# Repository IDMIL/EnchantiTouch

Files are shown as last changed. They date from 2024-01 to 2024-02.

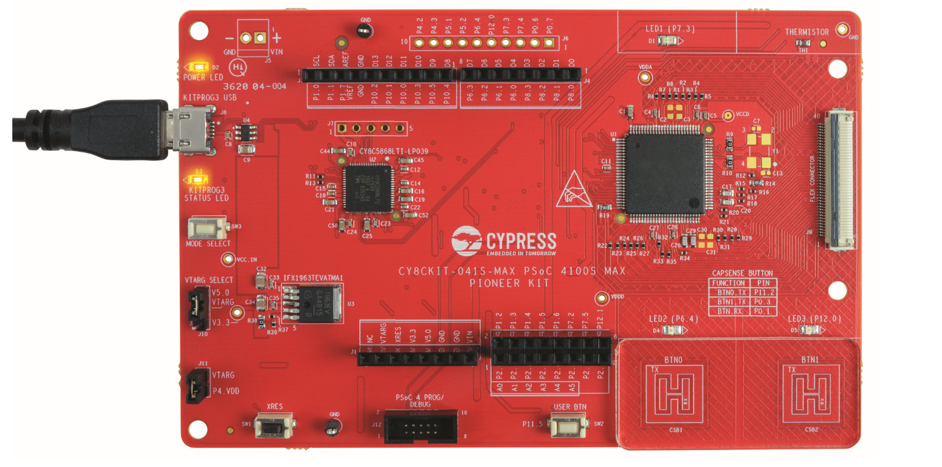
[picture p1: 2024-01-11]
firmware/tsticktouch_firmware/images/kit_connection.png

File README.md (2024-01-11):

# EnchantiTouch
This repository contains hardware files and firmware for the EnchantiTouch board. EnchantiTouch is a touch sensing board using Cypress' 4100S Max SoC. It supports up to 60 touch sensors through two 32 pin FFC connectors and multichannel scanning.

Branch archive-v0 features firmware for the first iteration of this board which did not have an SPI interface for communicating with a host MCU.

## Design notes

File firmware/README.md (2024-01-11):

# custom-touch-firmware
 Firmware for custom touch board for the T-Stick

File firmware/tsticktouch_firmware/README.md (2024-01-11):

# PSoC&trade; 4: Custom Touch Board for T-Stick

This code is meant to be used for collecting Touch Date to be sent to an external microcontroller. An additional touch board may be added vai SPI interface on the MCU

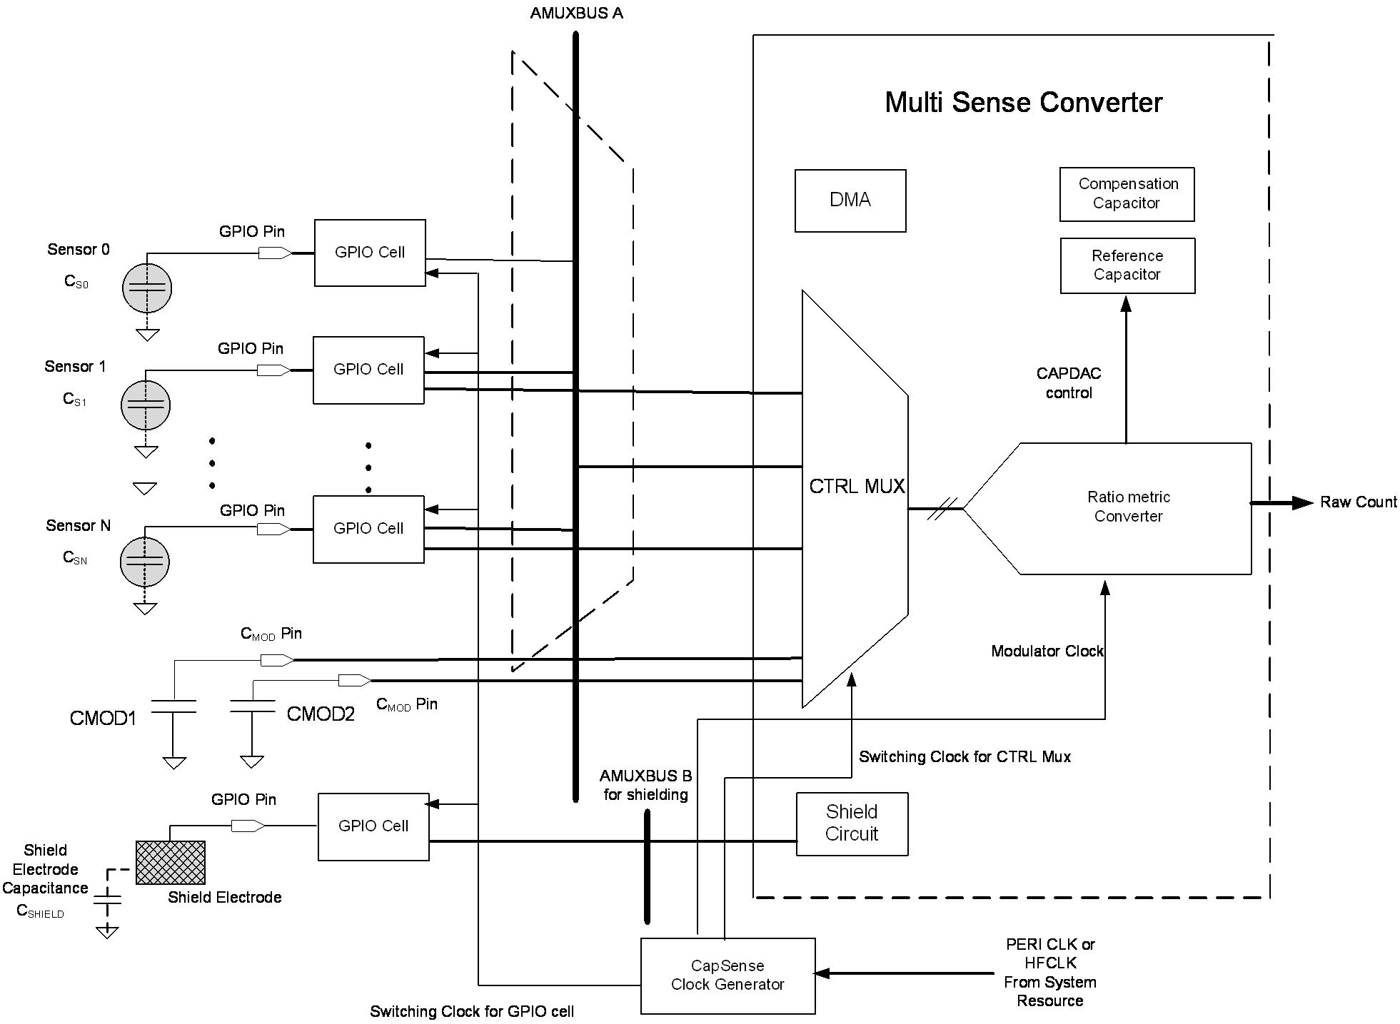
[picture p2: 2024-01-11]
firmware/tsticktouch_firmware/images/theory-blockdiagram.png

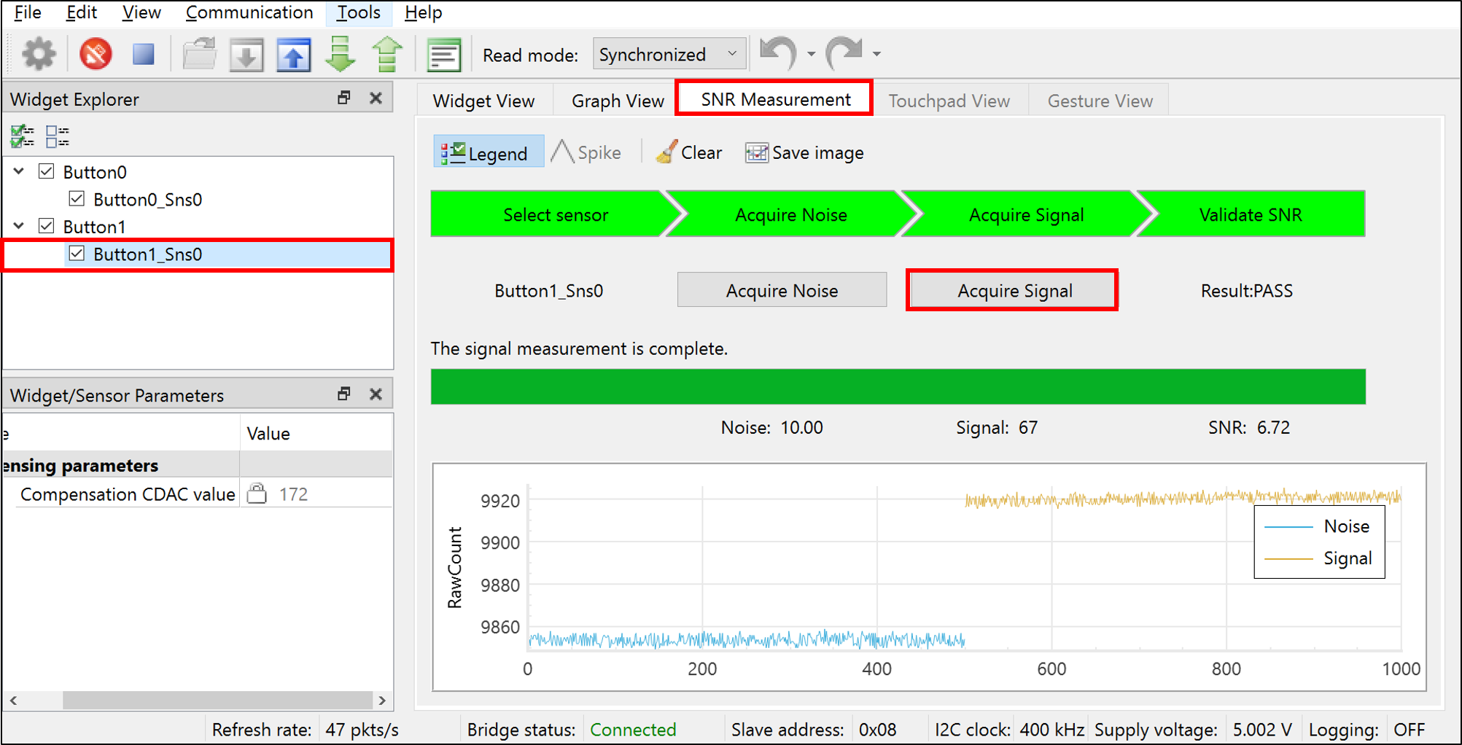
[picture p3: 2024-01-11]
firmware/tsticktouch_firmware/images/tuner-snr-pass.png

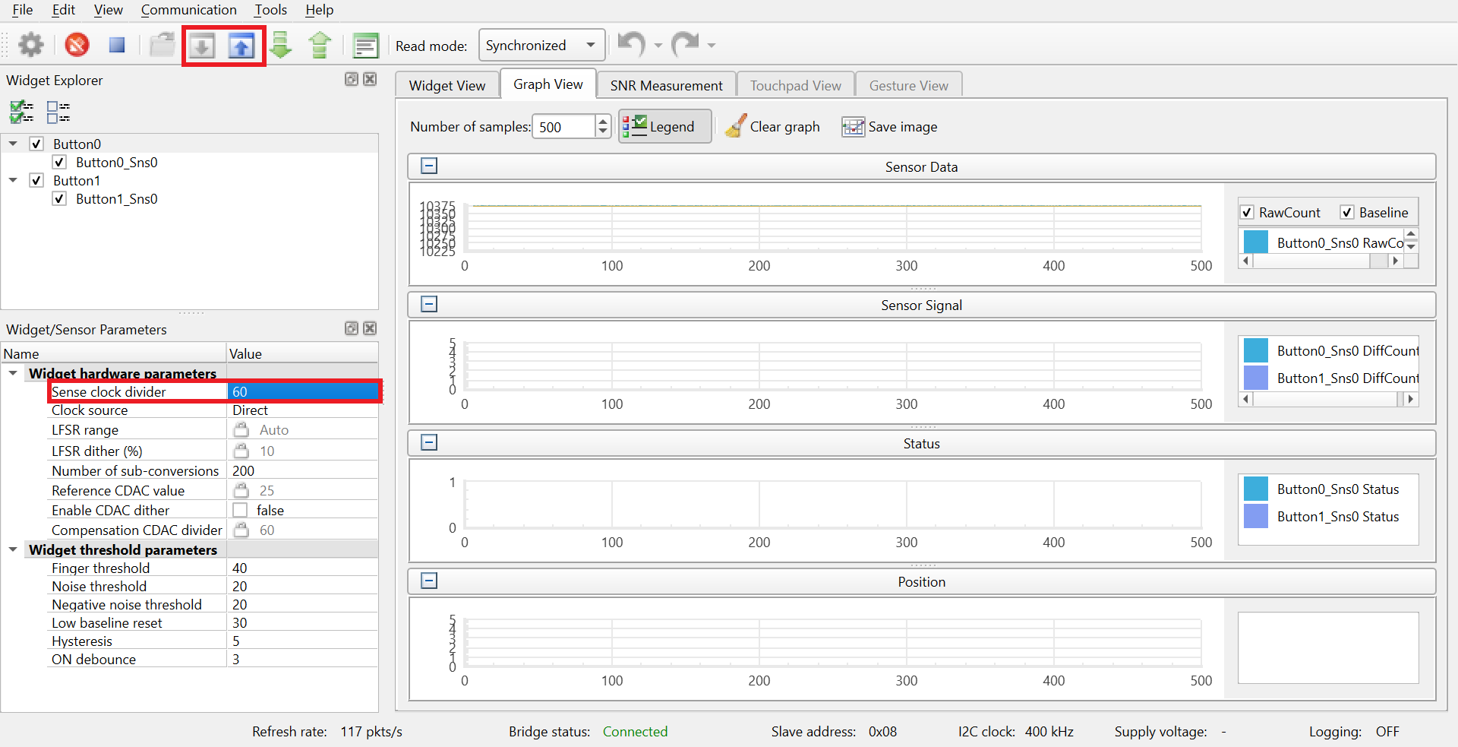
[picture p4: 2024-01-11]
firmware/tsticktouch_firmware/images/tuner-apply-to-device.png

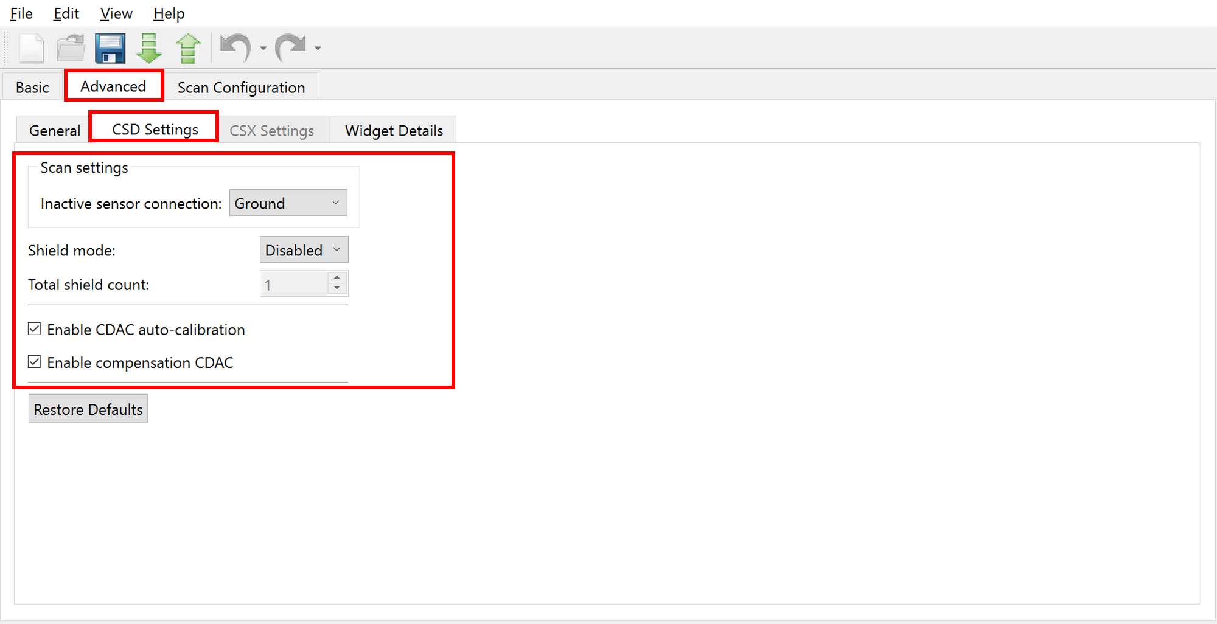
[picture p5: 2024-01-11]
firmware/tsticktouch_firmware/images/advanced-csd-settings.png

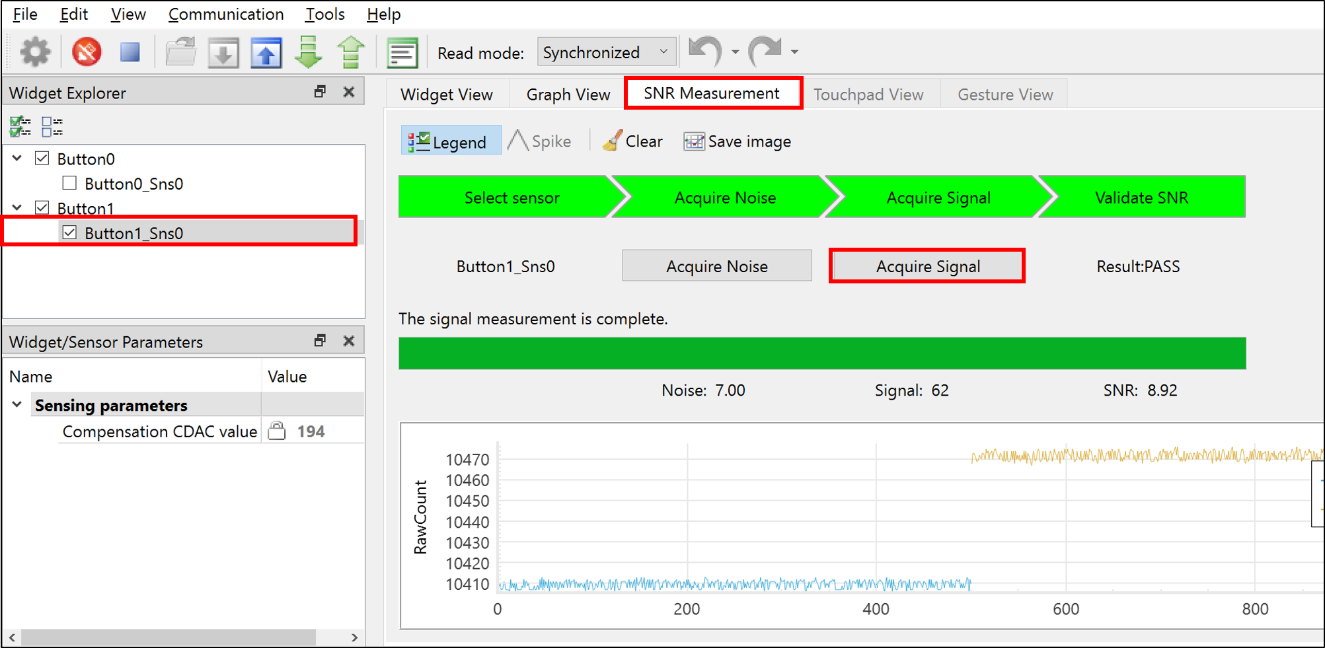
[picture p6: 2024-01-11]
firmware/tsticktouch_firmware/images/tuner-acquire-signal.png

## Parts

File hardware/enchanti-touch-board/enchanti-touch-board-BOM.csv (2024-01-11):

Manufacturer | MPN | Qty | Description | Reference(s) | Footprint
Murata Electronics | GCM155R71C104KA55J | 6 | 0.1 µF ±10% 16V Ceramic Capacitor X7R 0402 (1005 Metric) | C1, C10, C12, C14, C3, C5 | Capacitor_SMD:C_0402_1005Metric
Murata Electronics | GRM155R61C105KA12D | 6 | 1 µF ±10% 16V Ceramic Capacitor X5R 0402 (1005 Metric) | C11, C13, C15, C18, C2, C4 | Capacitor_SMD:C_0402_1005Metric
Murata Electronics | GRM155R71H222JA01J | 4 | 2200 pF ±5% 50V Ceramic Capacitor X7R 0402 (1005 Metric) | C6, C7, C8, C9 | Capacitor_SMD:C_0402_1005Metric
Micro Commercial Co | ESD5V0D5-TP | 1 | 18.6V Clamp 11.6A (8/20µs) Ipp Tvs Diode Surface Mount SOD-523 | D1 | Diode_SMD:D_SOD-523
JST Sales America Inc. | BM04B-SRSS-TB | 4 | Connector Header Surface Mount 4 position 0.039" (1.00mm) | GPIO1, GPIO2, GPIO3, GPIO4 | JST-footprints:JST_SH_BM04B-SRSS-TB_1x04-1MP_P1.00mm_Vertical
CNC Tech | 3220-10-0300-00 | 1 | Connector Header Surface Mount 10 position 0.050" (1.27mm) | J2 | Connector_PinHeader_1.27mm:PinHeader_2x05_P1.27mm_Vertical_SMD
Panasonic Electronic Components | ERJ-1GNF3300C | 2 | 330 Ohms ±1% 0.05W, 1/20W Chip Resistor 0201 (0603 Metric) Thick Film | R1, R2 | Resistor_SMD:R_0201_0603Metric
Panasonic Electronic Components | ERJ-1GNF5600C | 60 | 560 Ohms ±1% 0.05W, 1/20W Chip Resistor 0201 (0603 Metric) Thick Film | R3, R4, R5, R6, R7, R8, R9, R10, R11, R12, R13, R14, R15, R16, R17, R18, R19, R20, R21, R22, R23, R24, R25, R26, R27, R28, R29, R30, R31, R32, R33, R34, R35, R36, R37, R38, R39, R40, R41, R42, R43, R44, R45, R46, R47, R48, R49, R50, R51, R52, R53, R54, R55, R56, R57, R58, R59, R60, R61, R62 | Resistor_SMD:R_0201_0603Metric
Panasonic Electronic Components | ERJ-1GNF4701C | 2 | 4.7 kOhms ±1% 0.05W, 1/20W Chip Resistor 0201 (0603 Metric) Thick Film | R63, R64 | Resistor_SMD:R_0201_0603Metric
Molex | 54132-3262 | 2 | 32 Position FFC, FPC Connector Contacts, Bottom 0.020" (0.50mm) Surface Mount, Right Angle | TOUCH1, TOUCH2 | ffc_footprints:CON_541323262_MOL
Infineon Technologies | CY8C4149AZI-S598 | 1 | ARM® Cortex®-M0+ PSOC® 4 CY8C4100S Microcontroller IC 32-Bit 48MHz 384KB (384K x 8) FLASH 100-TQFP (14x14) | U1 | CY8C4149AZI-S598-footprints:QFP-100

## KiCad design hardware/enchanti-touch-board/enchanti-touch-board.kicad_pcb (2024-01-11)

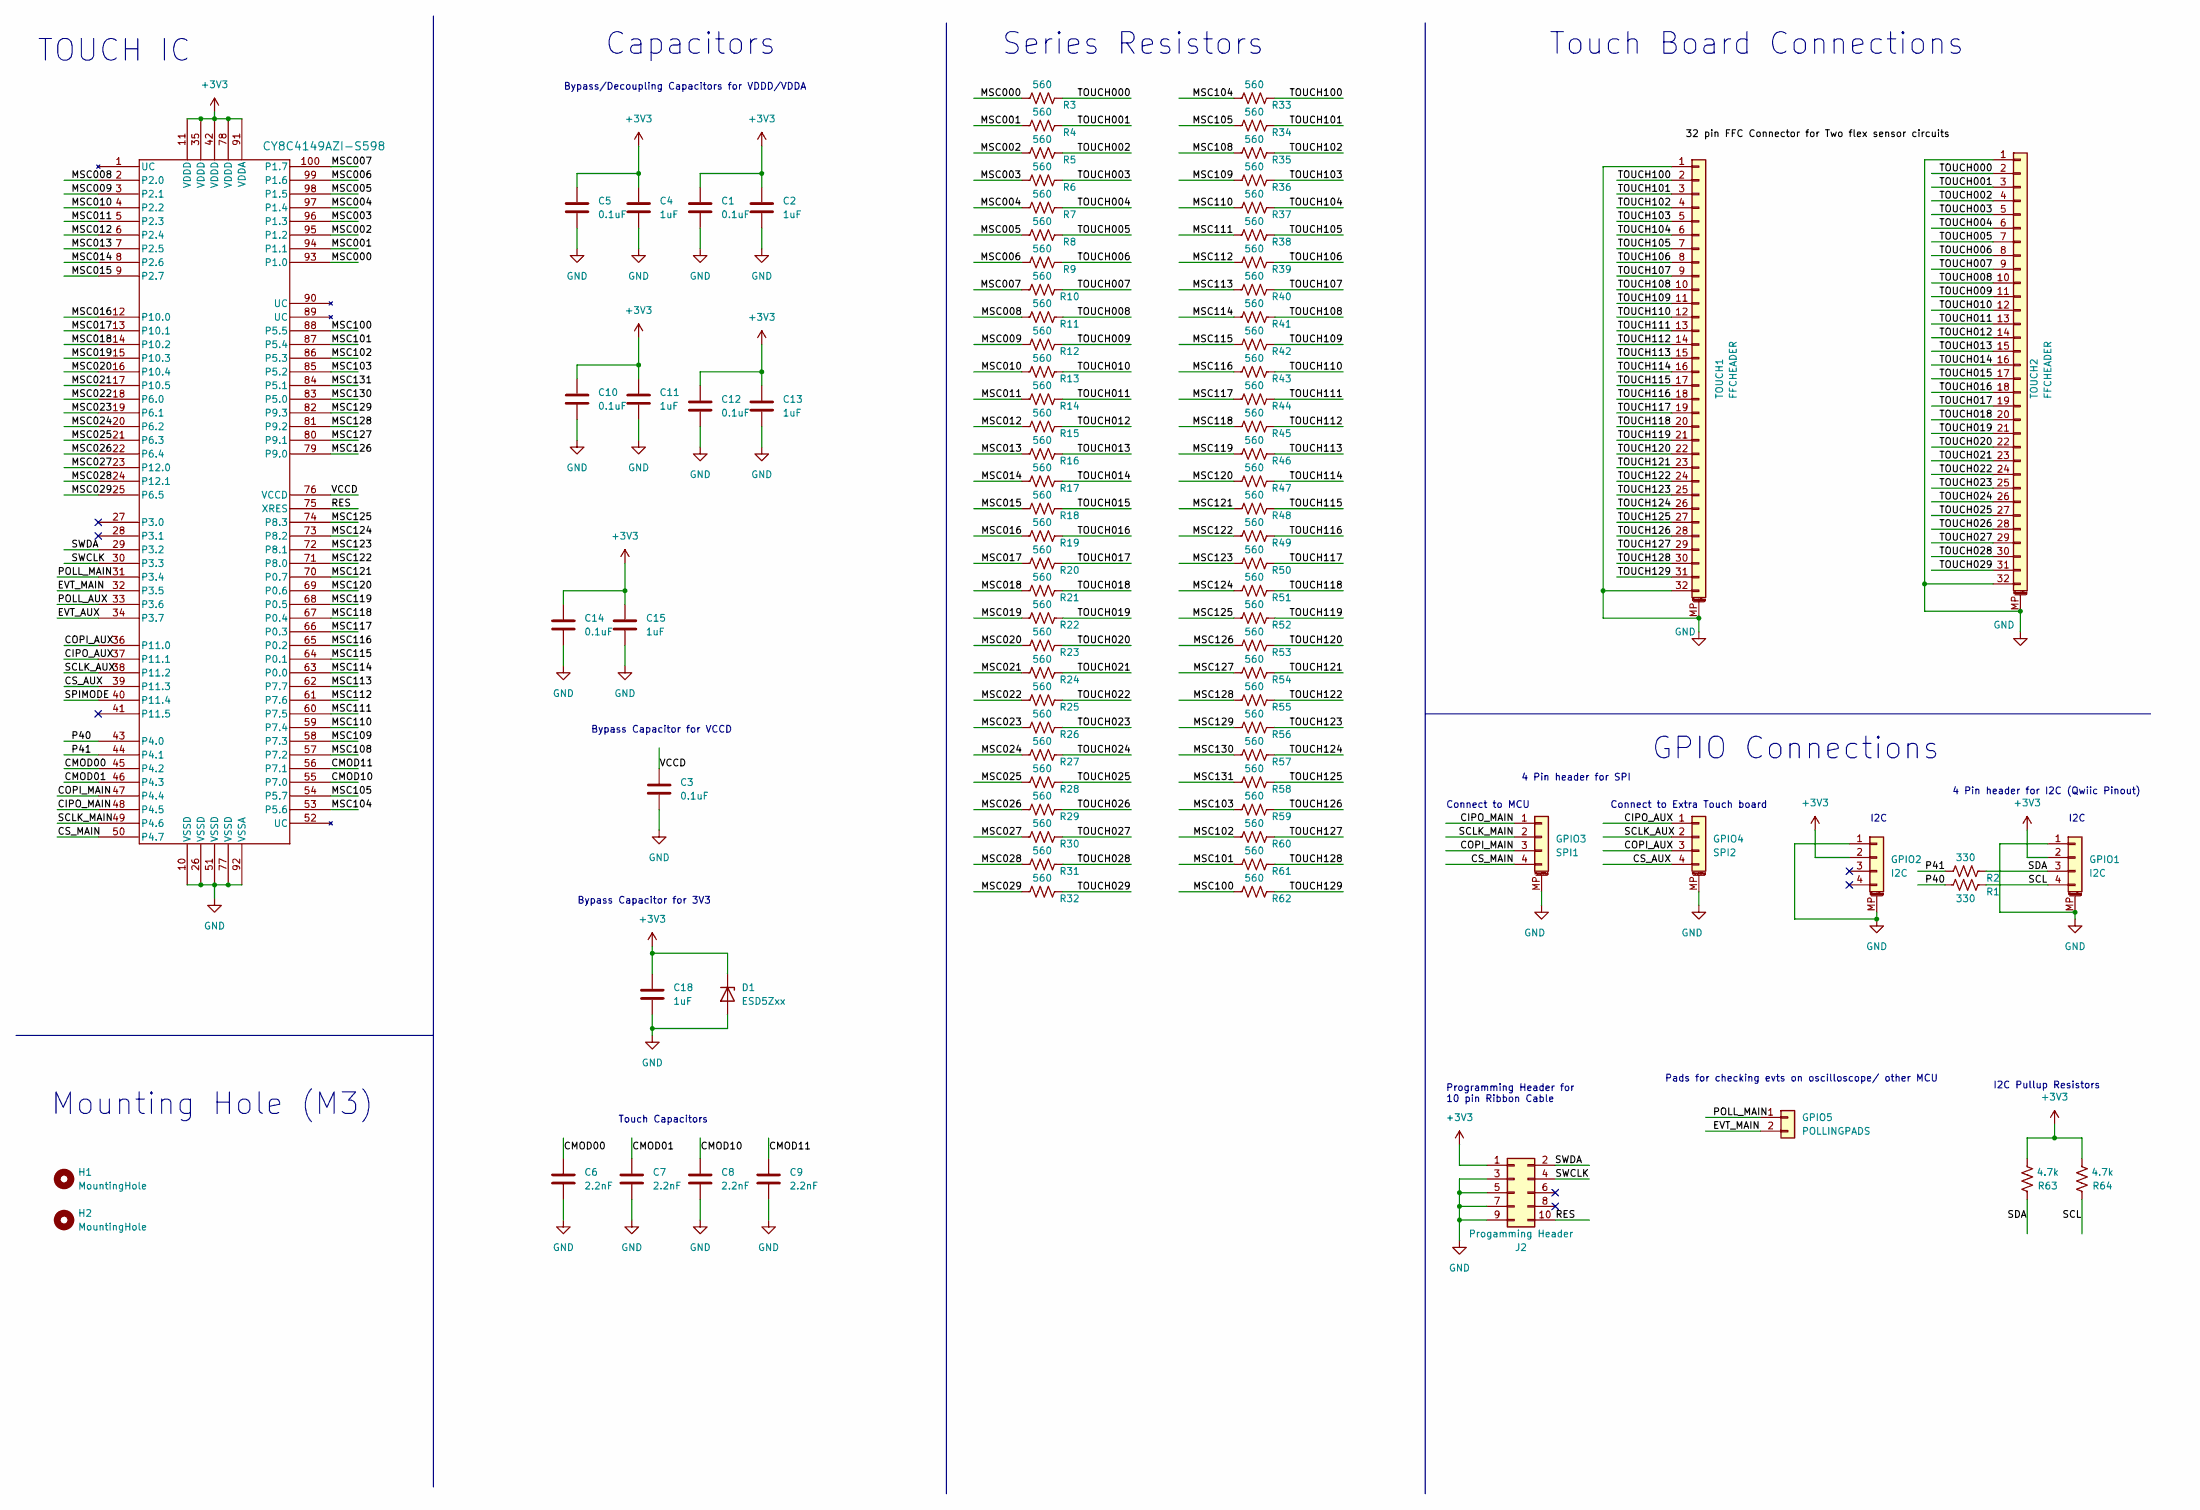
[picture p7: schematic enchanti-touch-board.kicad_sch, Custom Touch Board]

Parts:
C1, C3, C5, C10, C12, C14: 0.1uF; C_0402_1005Metric; MPN GCM155R71C104KA55J
C2, C4, C11, C13, C15, C18: 1uF; C_0402_1005Metric; MPN GRM155R61C105KA12D
C6, C7, C8, C9: 2.2nF; C_0402_1005Metric; MPN GRM155R71H222JA01J
D1: ESD5Zxx; D_SOD-523; MPN ESD5V0D5-TP
GPIO1, GPIO2: I2C; JST_SH_BM04B-SRSS-TB_1x04-1MP_P1.00mm_Vertical; MPN BM04B-SRSS-TB
GPIO3: SPI1; JST_SH_BM04B-SRSS-TB_1x04-1MP_P1.00mm_Vertical; MPN BM04B-SRSS-TB
GPIO4: SPI2; JST_SH_BM04B-SRSS-TB_1x04-1MP_P1.00mm_Vertical; MPN BM04B-SRSS-TB
GPIO5: POLLINGPADS; solderpads
H1, H2: MountingHole; MountingHole_3.2mm_M3
J2: Progamming Header; PinHeader_2x05_P1.27mm_Vertical_SMD; MPN 3220-10-0300-00
R1, R2: 330; R_0201_0603Metric; MPN ERJ-1GNF3300C
R3, R4, R5, R6, R7, R8, R9, R10, R11, R12, R13, R14, R15, R16, R17, R18, R19, R20, R21, R22, R23, R24, R25, R26, R27, R28, R29, R30, R31, R32, R33, R34, R35, R36, R37, R38, R39, R40, R41, R42, R43, R44, R45, R46, R47, R48, R49, R50, R51, R52, R53, R54, R55, R56, R57, R58, R59, R60, R61, R62: 560; R_0201_0603Metric; MPN ERJ-1GNF5600C
R63, R64: 4.7k; R_0201_0603Metric; MPN ERJ-1GNF4701C
TOUCH1, TOUCH2: FFCHEADER; CON_541323262_MOL; MPN 54132-3262
U1: CY8C4149AZI-S598; QFP-100; MPN CY8C4149AZI-S598

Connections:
+3V3: C1.2, C2.2, C4.2, C5.2, C10.2, C11.2, C12.2, C13.2, C14.2, C15.2, C18.2, D1.1 (K), GPIO1.2, GPIO2.2, J2.1, R63.2, R64.2, U1.11 (VDDD), U1.35 (VDDD), U1.42 (VDDD), U1.78 (VDDD), U1.91 (VDDA)
/CIPO_AUX: GPIO4.1, U1.37 (P11.1)
/CIPO_MAIN: GPIO3.1, U1.48 (P4.5)
/CMOD00: C6.2, U1.45 (P4.2)
/CMOD01: C7.2, U1.46 (P4.3)
/CMOD10: C8.2, U1.55 (P7.0)
/CMOD11: C9.2, U1.56 (P7.1)
/COPI_AUX: GPIO4.3, U1.36 (P11.0)
/COPI_MAIN: GPIO3.3, U1.47 (P4.4)
/CS_AUX: GPIO4.4, U1.39 (P11.3)
/CS_MAIN: GPIO3.4, U1.50 (P4.7)
/EVT_AUX: U1.34 (P3.7)
/EVT_MAIN: GPIO5.2, U1.32 (P3.5)
/MSC000: R3.1, U1.93 (P1.0)
/MSC001: R4.1, U1.94 (P1.1)
/MSC002: R5.1, U1.95 (P1.2)
/MSC003: R6.1, U1.96 (P1.3)
/MSC004: R7.1, U1.97 (P1.4)
/MSC005: R8.1, U1.98 (P1.5)
/MSC006: R9.1, U1.99 (P1.6)
/MSC007: R10.1, U1.100 (P1.7)
/MSC008: R11.1, U1.2 (P2.0)
/MSC009: R12.1, U1.3 (P2.1)
/MSC010: R13.1, U1.4 (P2.2)
/MSC011: R14.1, U1.5 (P2.3)
/MSC012: R15.1, U1.6 (P2.4)
/MSC013: R16.1, U1.7 (P2.5)
/MSC014: R17.1, U1.8 (P2.6)
/MSC015: R18.1, U1.9 (P2.7)
/MSC016: R19.1, U1.12 (P10.0)
/MSC017: R20.1, U1.13 (P10.1)
/MSC018: R21.1, U1.14 (P10.2)
/MSC019: R22.1, U1.15 (P10.3)
/MSC020: R23.1, U1.16 (P10.4)
/MSC021: R24.1, U1.17 (P10.5)
/MSC022: R25.1, U1.18 (P6.0)
/MSC023: R26.1, U1.19 (P6.1)
/MSC024: R27.1, U1.20 (P6.2)
/MSC025: R28.1, U1.21 (P6.3)
/MSC026: R29.1, U1.22 (P6.4)
/MSC027: R30.1, U1.23 (P12.0)
/MSC028: R31.1, U1.24 (P12.1)
/MSC029: R32.1, U1.25 (P6.5)
/MSC100: R62.1, U1.88 (P5.5)
/MSC101: R61.1, U1.87 (P5.4)
/MSC102: R60.1, U1.86 (P5.3)
/MSC103: R59.1, U1.85 (P5.2)
/MSC104: R33.1, U1.53 (P5.6)
/MSC105: R34.1, U1.54 (P5.7)
/MSC108: R35.1, U1.57 (P7.2)
/MSC109: R36.1, U1.58 (P7.3)
/MSC110: R37.1, U1.59 (P7.4)
/MSC111: R38.1, U1.60 (P7.5)
/MSC112: R39.1, U1.61 (P7.6)
/MSC113: R40.1, U1.62 (P7.7)
/MSC114: R41.1, U1.63 (P0.0)
/MSC115: R42.1, U1.64 (P0.1)
/MSC116: R43.1, U1.65 (P0.2)
/MSC117: R44.1, U1.66 (P0.3)
/MSC118: R45.1, U1.67 (P0.4)
/MSC119: R46.1, U1.68 (P0.5)
/MSC120: R47.1, U1.69 (P0.6)
/MSC121: R48.1, U1.70 (P0.7)
/MSC122: R49.1, U1.71 (P8.0)
/MSC123: R50.1, U1.72 (P8.1)
/MSC124: R51.1, U1.73 (P8.2)
/MSC125: R52.1, U1.74 (P8.3)
/MSC126: R53.1, U1.79 (P9.0)
/MSC127: R54.1, U1.80 (P9.1)
/MSC128: R55.1, U1.81 (P9.2)
/MSC129: R56.1, U1.82 (P9.3)
/MSC130: R57.1, U1.83 (P5.0)
/MSC131: R58.1, U1.84 (P5.1)
/P40: R1.1, U1.43 (P4.0)
/P41: R2.1, U1.44 (P4.1)
/POLL_AUX: U1.33 (P3.6)
/POLL_MAIN: GPIO5.1, U1.31 (P3.4)
/RES: J2.10, U1.75 (XRES)
/SCL: GPIO1.4, R1.2, R64.1
/SCLK_AUX: GPIO4.2, U1.38 (P11.2)
/SCLK_MAIN: GPIO3.2, U1.49 (P4.6)
/SDA: GPIO1.3, R2.2, R63.1
/SPIMODE: U1.40 (P11.4)
/SWCLK: J2.4, U1.30 (P3.3)
/SWDA: J2.2, U1.29 (P3.2)
/TOUCH000: R3.2, TOUCH2.2
/TOUCH001: R4.2, TOUCH2.3
/TOUCH002: R5.2, TOUCH2.4
/TOUCH003: R6.2, TOUCH2.5
/TOUCH004: R7.2, TOUCH2.6
/TOUCH005: R8.2, TOUCH2.7
/TOUCH006: R9.2, TOUCH2.8
/TOUCH007: R10.2, TOUCH2.9
/TOUCH008: R11.2, TOUCH2.10
/TOUCH009: R12.2, TOUCH2.11
/TOUCH010: R13.2, TOUCH2.12
/TOUCH011: R14.2, TOUCH2.13
/TOUCH012: R15.2, TOUCH2.14
/TOUCH013: R16.2, TOUCH2.15
/TOUCH014: R17.2, TOUCH2.16
/TOUCH015: R18.2, TOUCH2.17
/TOUCH016: R19.2, TOUCH2.18
/TOUCH017: R20.2, TOUCH2.19
/TOUCH018: R21.2, TOUCH2.20
/TOUCH019: R22.2, TOUCH2.21
/TOUCH020: R23.2, TOUCH2.22
/TOUCH021: R24.2, TOUCH2.23
/TOUCH022: R25.2, TOUCH2.24
/TOUCH023: R26.2, TOUCH2.25
/TOUCH024: R27.2, TOUCH2.26
/TOUCH025: R28.2, TOUCH2.27
/TOUCH026: R29.2, TOUCH2.28
/TOUCH027: R30.2, TOUCH2.29
/TOUCH028: R31.2, TOUCH2.30
/TOUCH029: R32.2, TOUCH2.31
/TOUCH100: R33.2, TOUCH1.2
/TOUCH101: R34.2, TOUCH1.3
/TOUCH102: R35.2, TOUCH1.4
/TOUCH103: R36.2, TOUCH1.5
/TOUCH104: R37.2, TOUCH1.6
/TOUCH105: R38.2, TOUCH1.7
/TOUCH106: R39.2, TOUCH1.8
/TOUCH107: R40.2, TOUCH1.9
/TOUCH108: R41.2, TOUCH1.10
/TOUCH109: R42.2, TOUCH1.11
/TOUCH110: R43.2, TOUCH1.12
/TOUCH111: R44.2, TOUCH1.13
/TOUCH112: R45.2, TOUCH1.14
/TOUCH113: R46.2, TOUCH1.15
/TOUCH114: R47.2, TOUCH1.16
/TOUCH115: R48.2, TOUCH1.17
/TOUCH116: R49.2, TOUCH1.18
/TOUCH117: R50.2, TOUCH1.19
/TOUCH118: R51.2, TOUCH1.20
/TOUCH119: R52.2, TOUCH1.21
/TOUCH120: R53.2, TOUCH1.22
/TOUCH121: R54.2, TOUCH1.23
/TOUCH122: R55.2, TOUCH1.24
/TOUCH123: R56.2, TOUCH1.25
/TOUCH124: R57.2, TOUCH1.26
/TOUCH125: R58.2, TOUCH1.27
/TOUCH126: R59.2, TOUCH1.28
/TOUCH127: R60.2, TOUCH1.29
/TOUCH128: R61.2, TOUCH1.30
/TOUCH129: R62.2, TOUCH1.31
/VCCD: C3.2, U1.76 (VCCD)
GND: C1.1, C2.1, C3.1, C4.1, C5.1, C6.1, C7.1, C8.1, C9.1, C10.1, C11.1, C12.1, C13.1, C14.1, C15.1, C18.1, D1.2 (A), GPIO1.1, GPIO1.MP (MountPin), GPIO2.1, GPIO2.MP (MountPin), GPIO3.MP (MountPin), GPIO4.MP (MountPin), J2.3, J2.5, J2.7, J2.9, TOUCH1.1, TOUCH1.32, TOUCH1.MP (MountPin), TOUCH2.1, TOUCH2.32, TOUCH2.MP (MountPin), U1.10 (VSSD), U1.26 (VSSD), U1.51 (VSSD), U1.77 (VSSD), U1.92 (VSSA)

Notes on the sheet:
Bypass Capacitor for VCCD
Touch Board Connections
I2C
Connect to Extra Touch board
Capacitors
Bypass/Decoupling Capacitors for VDDD/VDDA
Pads for checking evts on oscilloscope/ other MCU
GPIO Connections
Bypass Capacitor for 3V3
Mounting Hole (M3)
Connect to MCU
Touch Capacitors
4 Pin header for SPI
Series Resistors
I2C Pullup Resistors
4 Pin header for I2C (Qwiic Pinout)
TOUCH IC
Programming Header for 10 pin Ribbon Cable

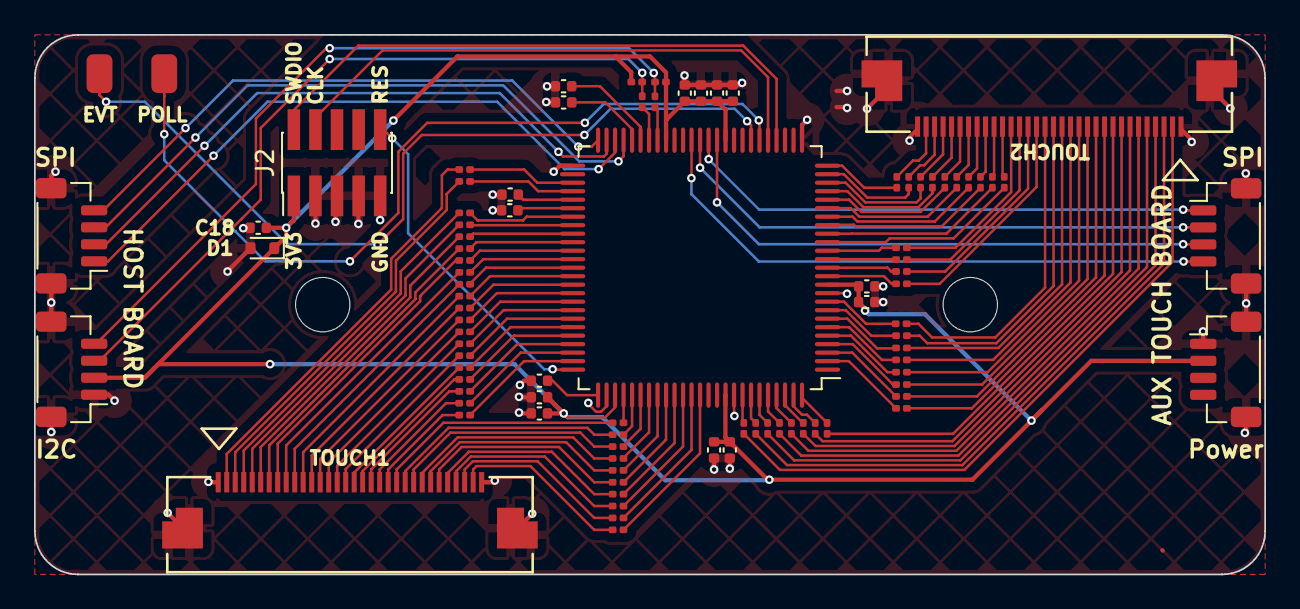
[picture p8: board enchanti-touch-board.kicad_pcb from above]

Board: 2 copper layers, 72.4 x 31.8 mm, 92 parts (0 on the bottom side), 144 nets.

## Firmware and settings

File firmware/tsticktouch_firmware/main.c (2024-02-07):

/******************************************************************************
* File Name: main.c
*
* Description: This is the source code for the PSoC 4 MSC CapSense CSD Button
* Tuning code example for ModusToolbox.
*
* Related Document: See README.md
*
*******************************************************************************
* Copyright 2021-2023, Cypress Semiconductor Corporation (an Infineon company) or
* an affiliate of Cypress Semiconductor Corporation.  All rights reserved.
*
* This software, including source code, documentation and related
* materials ("Software") is owned by Cypress Semiconductor Corporation
* or one of its affiliates ("Cypress") and is protected by and subject to
* worldwide patent protection (United States and foreign),
* United States copyright laws and international treaty provisions.
* Therefore, you may use this Software only as provided in the license
* agreement accompanying the software package from which you
* obtained this Software ("EULA").
* If no EULA applies, Cypress hereby grants you a personal, non-exclusive,
* non-transferable license to copy, modify, and compile the Software
* source code solely for use in connection with Cypress's
* integrated circuit products.  Any reproduction, modification, translation,
* compilation, or representation of this Software except as specified
* above is prohibited without the express written permission of Cypress.
*
* Disclaimer: THIS SOFTWARE IS PROVIDED AS-IS, WITH NO WARRANTY OF ANY KIND,
* EXPRESS OR IMPLIED, INCLUDING, BUT NOT LIMITED TO, NONINFRINGEMENT, IMPLIED
* WARRANTIES OF MERCHANTABILITY AND FITNESS FOR A PARTICULAR PURPOSE. Cypress
* reserves the right to make changes to the Software without notice. Cypress
* does not assume any liability arising out of the application or use of the
* Software or any product or circuit described in the Software. Cypress does
* not authorize its products for use in any products where a malfunction or
* failure of the Cypress product may reasonably be expected to result in
* significant property damage, injury or death ("High Risk Product"). By
* including Cypress's product in a High Risk Product, the manufacturer
* of such system or application assumes all risk of such use and in doing
* so agrees to indemnify Cypress against all liability.
*******************************************************************************/


/*******************************************************************************
 * Include header files
 ******************************************************************************/
#include "cy_pdl.h"
#include "cy_scb_spi.h"
#include "cybsp.h"
#include "cycfg.h"
#include "cycfg_capsense.h"
#include "cycfg_peripherals.h"
#include <stdint.h>
#include <stdio.h>
#include <time.h>
#include <sys/time.h>
#include <cy_systick.h>

/*******************************************************************************
* Macros
*******************************************************************************/
#define CAPSENSE_MSC0_INTR_PRIORITY      (3u)
#define CAPSENSE_MSC1_INTR_PRIORITY      (3u)
#define CY_ASSERT_FAILED                 (0u)
#define MSC_CAPSENSE_WIDGET_INACTIVE     (0u)

/* EZI2C interrupt priority must be higher than CapSense interrupt. */
#define EZI2C_INTR_PRIORITY              (2u)
#define SPI_INTR_PRIORITY                (2u)
#define SPI_AUX_INTR_PRIORITY            (2u)

/* Define Board Mode Macros*/
#define TOUCHSIZE (60u)
#define MAIN_TOUCH_BOARD (0u)
#define AUX_TOUCH_BOARD (1u)
#define SPI_TIMEOUT (1000)
#define SPI_BUFFERSIZE (128u)

/*******************************************************************************
* Global Variables
********************************************************************************/
cy_stc_scb_ezi2c_context_t ezi2c_context;
#if CY_CAPSENSE_BIST_EN
/* Variables to hold sensor parasitic capacitances and status*/
uint32_t button0_cp = 0, button1_cp = 0;
cy_en_capsense_bist_status_t button0_cp_status, button1_cp_status;
#endif /* CY_CAPSENSE_BIST_EN */
/* New touch variable (set to 1 if there is new touch data to send) **/
uint16_t newData = 0;
/* Touch data buffers*/
// Use 8bit subaddress size
typedef struct touchBuffer
{    
    uint8_t u8_reserve;                                    // addr 0, reserved for further use,
    uint8_t u8_boardmode;                                  // addr 1, is it the main board or aux board,
    uint8_t u8_numboards;                                  // addr 2, number of boards,
    uint8_t u8_touchmode;                                  // addr 3, reserved for further use,
    uint16_t u16_signal[TOUCHSIZE];                        // addr 4 - 124,
}touchBuffer;	

struct touchBuffer touch1Data; // Main board touch data
struct touchBuffer touch2Data; // Auxillary board touch data


/* Timing variables */
int start, end; // timing variable
float slot_scan_time = 0;
float sensor_scan_time = 0;
uint16_t scan_time = 0;
float total_t = 0;
int systick_count = 0;
float TRIALS = 20000.0f;
int SENSORS_PER_TRIAL = 30.0f;

/* Allocate context for SPI operation */
cy_stc_scb_spi_context_t spiContext;
cy_stc_scb_spi_context_t spi_aux_Context;
unsigned long transfer_status;
uint32_t bytes_transferred;
uint32_t spi_main_count;
uint32_t spi_aux_count;
uint16_t txBuffer[SPI_BUFFERSIZE];
uint16_t rxBuffer[SPI_BUFFERSIZE];
/* Define SPI Mode
    0 = Main board
    1 = Aux Board
*/
uint32_t BOARD_MODE = 0;
uint32_t ENABLE_SPI = 0;

/*******************************************************************************
* Function Prototypes
*******************************************************************************/
static void initialize_capsense(void);
static void capsense_msc0_isr(void);
static void capsense_msc1_isr(void);
static void saveTouchData(void);
static void ezi2c_isr(void);
static void spi_isr(void);
static void spi_aux_isr(void);
static void initialize_i2c(void);
static void initialize_spi(void);
static void getTouch(void);
static void sendTouch(void);
static float timedifference_msec(void);
static float timedifference_usec(void);
static void systick_isr(void);
static uint32_t get_tick(void);

#if CY_CAPSENSE_BIST_EN
static void measure_sensor_cp(void);
#endif /* CY_CAPSENSE_BIST_EN */

/*******************************************************************************
* Function Name: main
********************************************************************************
* Summary:
*  System entrance point. This function performs
*  - initial setup of device
*  - initialize CapSense
*  - perform Cp measurement if Built-in Self test (BIST) is enabled
*  - scan touch input continuously
*
* Return:
*  int
*
*******************************************************************************/
int main(void)
{
    cy_rslt_t result = CY_RSLT_SUCCESS;

    /* Initialize the device and board peripherals */
    result = cybsp_init();

    /* Board init failed. Stop program execution */
    if (result != CY_RSLT_SUCCESS)
    {
        CY_ASSERT(CY_ASSERT_FAILED);
    }

    /* Enable global interrupts */
    __enable_irq();

    /* Enable timer */
    Cy_SysTick_Init(CY_SYSTICK_CLOCK_SOURCE_CLK_CPU, 0x00FFFFFF);
    Cy_SysTick_SetCallback(0UL, &systick_isr);

    /* touch buffer Initialization */
    uint16_t i;  

    touch1Data.u8_reserve = 0x00u; 
    touch1Data.u8_boardmode = 0x00u;
    touch1Data.u8_numboards = 0x01u;
    touch1Data.u8_touchmode = 0x00u;   
    touch2Data.u8_reserve = 0x00u;   
    touch2Data.u8_boardmode = 0x00u;
    touch2Data.u8_numboards = 0x01u;
    touch2Data.u8_touchmode = 0x00u; 
    for(i=0; i<TOUCHSIZE; i++)
    {   
        // Main touch buffer
        touch1Data.u16_signal[i]   = 0x0000u;

        // Aux touch buffer
        touch2Data.u16_signal[i]   = 0x0000u;
    }

    /* Initialise SPI buffer*/
    for(i=0; i<SPI_BUFFERSIZE; i++)
    {   
        // Main touch buffer
        txBuffer[i]   = 0x0000u;
    }

    /* Initialize EZI2C */
    initialize_i2c();

    /* Initialize SPI*/
    initialize_spi();

    /* Initialize MSC CapSense */
    initialize_capsense();

#if CY_CAPSENSE_BIST_EN
    /* Measure the self capacitance of sensor electrode using BIST */
    measure_sensor_cp();
#endif /* CY_CAPSENSE_BIST_EN */
    /* start time */
    start = Cy_SysTick_GetValue();

    /* Start the first scan */
    Cy_CapSense_ScanAllSlots(&cy_capsense_context);

    for (;;)
    {
        if(CY_CAPSENSE_NOT_BUSY == Cy_CapSense_IsBusy(&cy_capsense_context))
        {
            /* Process all widgets */
            Cy_CapSense_ProcessAllWidgets(&cy_capsense_context);

            // /* Save touch data to touch buffers */
            saveTouchData();
            
            /* Start the next scan */
            Cy_CapSense_ScanAllSlots(&cy_capsense_context);

            /* If there are more than one touchboards get SPI data from them */
            if (touch1Data.u8_numboards > 1){
                getTouch();
            }

            /* Compute sensor scan time */
            end = get_tick();
            total_t = timedifference_usec();
            scan_time = (uint16_t)total_t;
            start = end;

            /* Send data to host MCU */
            sendTouch();

            // /* Toggles GPIO for refresh rate measurement. Probe at P3.4. */
            Cy_GPIO_Inv(CYBSP_SENSE_SCAN_RATE_PORT, CYBSP_SENSE_SCAN_RATE_NUM);

            // /* Sends interrupt if there is touch data */
            if (newData) {
                Cy_GPIO_Inv(CYBSP_EVT_PORT, CYBSP_EVT_NUM);
                newData = 0;
            }                
        }
    }
    // /* update time */
    // end = get_tick();
    // total_t = timedifference_sec();
    // slot_scan_time = 1000 * total_t / TRIALS; // scan time per 30 sensors (us)
    // sensor_scan_time = slot_scan_time / SENSORS_PER_TRIAL; // scan time per sensor (us)
    // printf("Time taken to scan %d sensors %f times: %f ms", SENSORS_PER_TRIAL, TRIALS, total_t);
}


/*******************************************************************************
* Function Name: get tick
********************************************************************************
* Summary:
*  Get current systick value
*
*******************************************************************************/

static uint32_t get_tick(void)
{
    return ((0xFFFFFF - Cy_SysTick_GetValue()) + (systick_count * 0x1000000));
}

/*******************************************************************************
* Function Name: timedifference_msec
********************************************************************************
* Summary:
*  This function returns the time difference in ms
*
*******************************************************************************/

static float timedifference_msec(void)
{
    int tick_dif = end - start;
    if (tick_dif < 0) {
        tick_dif = -1 * tick_dif;
    }
    float time_diff = tick_dif * 1000.0f;
    time_diff = time_diff / 16777216.0f;
    return time_diff;
}

/*******************************************************************************
* Function Name: timedifference_msec
********************************************************************************
* Summary:
*  This function returns the time difference in ms
*
*******************************************************************************/

static float timedifference_usec(void)
{
    int tick_dif = end - start;
    if (tick_dif < 0) {
        tick_dif = -1 * tick_dif;
    }
    float time_diff = tick_dif * 1000000.0f;
    time_diff = time_diff / 16777216.0f;
    return time_diff;
}


/*******************************************************************************
* Function Name: SysTick_Callback
****************************************************************************/
static void systick_isr(void)
{
    /* Some action */
    systick_count++;
}

/*******************************************************************************
* Function Name: initialize_capsense
********************************************************************************
* Summary:
*  This function initializes the CapSense and configures the CapSense
*  interrupt.
*
*******************************************************************************/
static void initialize_capsense(void)
{
    cy_capsense_status_t status = CY_CAPSENSE_STATUS_SUCCESS;

    /* CapSense interrupt configuration MSC 0 */
    const cy_stc_sysint_t capsense_msc0_interrupt_config =
    {
        .intrSrc = CY_MSC0_IRQ,
        .intrPriority = CAPSENSE_MSC0_INTR_PRIORITY,
    };

    /* CapSense interrupt configuration MSC 1 */
    const cy_stc_sysint_t capsense_msc1_interrupt_config =
    {
        .intrSrc = CY_MSC1_IRQ,
        .intrPriority = CAPSENSE_MSC1_INTR_PRIORITY,
    };

    /* Capture the MSC HW block and initialize it to the default state. */
    status = Cy_CapSense_Init(&cy_capsense_context);

    if (CY_CAPSENSE_STATUS_SUCCESS == status)
    {
        /* Initialize CapSense interrupt for MSC 0 */
        Cy_SysInt_Init(&capsense_msc0_interrupt_config, capsense_msc0_isr);
        NVIC_ClearPendingIRQ(capsense_msc0_interrupt_config.intrSrc);
        NVIC_EnableIRQ(capsense_msc0_interrupt_config.intrSrc);

        /* Initialize CapSense interrupt for MSC 1 */
        Cy_SysInt_Init(&capsense_msc1_interrupt_config, capsense_msc1_isr);
        NVIC_ClearPendingIRQ(capsense_msc1_interrupt_config.intrSrc);
        NVIC_EnableIRQ(capsense_msc1_interrupt_config.intrSrc);

        /* Initialize the CapSense firmware modules. */
        status = Cy_CapSense_Enable(&cy_capsense_context);
    }

    if(status != CY_CAPSENSE_STATUS_SUCCESS)
    {
        /* This status could fail before tuning the sensors correctly.
         * Ensure that this function passes after the CapSense sensors are tuned
         * as per procedure give in the Readme.md file */
    }
}


/*******************************************************************************
* Function Name: capsense_msc0_isr
********************************************************************************
* Summary:
*  Wrapper function for handling interrupts from CapSense MSC0 block.
*
*******************************************************************************/
static void capsense_msc0_isr(void)
{
    Cy_CapSense_InterruptHandler(CY_MSC0_HW, &cy_capsense_context);

    uint32_t intrStatus;
    /* Read interrupt status register */
    intrStatus = Cy_MSC_ReadReg(MSC0, CY_MSC_REG_OFFSET_INTR);
    /* Check an event that triggered the interrupt */
    if ((intrStatus & MSC_INTR_SET_SCAN_Msk) == MSC_INTR_SET_SCAN_Msk)
    {
        /* End of scan occurred, get the result and do something with it here */
    }
    /* Clear pending interrupt */
    Cy_MSC_WriteReg(MSC0, CY_MSC_REG_OFFSET_INTR, intrStatus);
    (void)Cy_MSC_ReadReg(MSC0, CY_MSC_REG_OFFSET_INTR);
}


/*******************************************************************************
* Function Name: capsense_msc1_isr
********************************************************************************
* Summary:
*  Wrapper function for handling interrupts from CapSense MSC1 block.
*
*******************************************************************************/
static void capsense_msc1_isr(void)
{
    Cy_CapSense_InterruptHandler(CY_MSC1_HW, &cy_capsense_context);
}

/*******************************************************************************
* Function Name: saveTouchData(void)
********************************************************************************
* Summary:
*  Function for saving touch data to touch data buffers
*
*******************************************************************************/
static void saveTouchData(void){
    uint16_t i;
    for(i=0;i<TOUCHSIZE;i++)
    {
        if (i < 30) {
            if (touch1Data.u16_signal[59-i] != cy_capsense_tuner.sensorContext[i].diff) {
                newData = 1;
            }
            touch1Data.u16_signal[59-i] = cy_capsense_tuner.sensorContext[i].diff;
        } else if (i >= 30) {
            if (touch1Data.u16_signal[i-30] != cy_capsense_tuner.sensorContext[i].diff) {
                newData = 1;
            }
            touch1Data.u16_signal[i-30] = cy_capsense_tuner.sensorContext[i].diff;
        }
        
    }
}


/*******************************************************************************
* Function Name: initialize_i2c
********************************************************************************
* Summary:
* EZI2C module to communicate with the CapSense Tuner tool.
*
*******************************************************************************/
static void initialize_i2c(void)
{
    cy_en_scb_ezi2c_status_t status = CY_SCB_EZI2C_SUCCESS;

    /* EZI2C interrupt configuration structure */
    const cy_stc_sysint_t ezi2c_intr_config =
    {
        .intrSrc = CYBSP_EZI2C_IRQ,
        .intrPriority = EZI2C_INTR_PRIORITY,
    };

    /* Initialize the EzI2C firmware module */
    status = Cy_SCB_EZI2C_Init(CYBSP_EZI2C_HW, &CYBSP_EZI2C_config, &ezi2c_context);

    if(status != CY_SCB_EZI2C_SUCCESS)
    {
        CY_ASSERT(CY_ASSERT_FAILED);
    }

    Cy_SysInt_Init(&ezi2c_intr_config, ezi2c_isr);
    NVIC_EnableIRQ(ezi2c_intr_config.intrSrc);

    /* Set the CapSense data structure as the I2C buffer to be exposed to the
     * master on primary slave address interface. Any I2C host tools such as
     * the Tuner or the Bridge Control Panel can read this buffer but you can
     * connect only one tool at a time.
     */
    Cy_SCB_EZI2C_SetBuffer1(CYBSP_EZI2C_HW, (uint8_t *)&touch1Data,
                            sizeof(touch1Data), sizeof(touch1Data),
                            &ezi2c_context);
    Cy_SCB_EZI2C_SetBuffer2(CYBSP_EZI2C_HW, (uint8_t *)&touch2Data,
                            sizeof(touch2Data), sizeof(touch2Data),
                            &ezi2c_context);

    Cy_SCB_EZI2C_Enable(CYBSP_EZI2C_HW);
}

/*******************************************************************************
* Function Name: ezi2c_isr
********************************************************************************
* Summary:
* Wrapper function for handling interrupts from EZI2C block.
*
*******************************************************************************/
static void ezi2c_isr(void)
{
    Cy_SCB_EZI2C_Interrupt(CYBSP_EZI2C_HW, &ezi2c_context);
}


/*******************************************************************************
* Function Name: initialize_spi
********************************************************************************
* Summary:
* Initialise the SPI comms in master/slave mode
*
*******************************************************************************/
static void initialize_spi(void)
{
    cy_en_scb_spi_status_t status = CY_SCB_SPI_SUCCESS;

    /* Init SPI */
    // Initialise SPI Slave device
    status = Cy_SCB_SPI_Init(CYBSP_SPI_HW, &CYBSP_SPI_config, &spiContext);

    // Initialise SPI Master device
    status = Cy_SCB_SPI_Init(CYBSP_SPI_AUX_HW, &CYBSP_SPI_AUX_config, &spi_aux_Context);

    if(status != CY_SCB_SPI_SUCCESS)
    {
        CY_ASSERT(CY_ASSERT_FAILED);
    }

    /* Populate configuration structure */
    const cy_stc_sysint_t spi_main_IntrConfig =
    {
        .intrSrc      = CYBSP_SPI_IRQ,
        .intrPriority = SPI_INTR_PRIORITY,
    };

    /* Populate configuration structure */
    const cy_stc_sysint_t spi_aux_IntrConfig =
    {
        .intrSrc      = CYBSP_SPI_AUX_IRQ,
        .intrPriority = SPI_AUX_INTR_PRIORITY,
    };

    /* Enable Interrupts*/
    Cy_SysInt_Init(&spi_main_IntrConfig, &spi_isr);
    Cy_SysInt_Init(&spi_aux_IntrConfig, &spi_aux_isr);

    NVIC_EnableIRQ(CYBSP_SPI_IRQ);
    NVIC_EnableIRQ(CYBSP_SPI_AUX_IRQ);

    /* Enable SPI to operate */
    Cy_SCB_SPI_Enable(CYBSP_SPI_HW);
    Cy_SCB_SPI_Enable(CYBSP_SPI_AUX_HW);
}

/*******************************************************************************
* Function Name: spi_isr
********************************************************************************
* Summary:
* Wrapper function for handling interrupts from SPI block.
*
*******************************************************************************/
static void spi_isr(void)
{
    Cy_SCB_SPI_Interrupt(CYBSP_SPI_HW, &spiContext);
}

/*******************************************************************************
* Function Name: spi_aux_isr
********************************************************************************
* Summary:
* Wrapper function for handling interrupts from SPI block.
*
*******************************************************************************/
static void spi_aux_isr(void)
{
    Cy_SCB_SPI_Interrupt(CYBSP_SPI_AUX_HW, &spi_aux_Context);
}

/*******************************************************************************
* Function Name: getTouch
********************************************************************************
* Summary:
* Function to get touch data over SPI
*
*******************************************************************************/
static void getTouch(void)
{
    if (0UL == (CY_SCB_SPI_TRANSFER_ACTIVE & Cy_SCB_SPI_GetTransferStatus(CYBSP_SPI_AUX_HW, &spi_aux_Context))) {
        /* Abort any ongoing transaction */
        Cy_SCB_SPI_AbortTransfer(CYBSP_SPI_AUX_HW, &spi_aux_Context);
        
        /* Save data to touch buffer*/
        for(int i=0; i<TOUCHSIZE; i++)
        {   
            touch2Data.u16_signal[i] = rxBuffer[i];
        }

        /* empty receive buffer */
        for(int i=0; i<TOUCHSIZE; i++)
        {   
            rxBuffer[i] = 0;
            rxBuffer[i+60] = 0;
        }
        /* Master: start a transfer. Slave: prepare for a transfer. */
        Cy_SCB_SPI_Transfer(CYBSP_SPI_AUX_HW, NULL, (uint8_t *)&rxBuffer, sizeof(rxBuffer), &spi_aux_Context);
    }
}
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

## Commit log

2024-01-11 moved firmware files to the right folder
    [PCBWay_positions.csv, enchanti-touch-board-BOM.csv, enchanti-touch-board.kicad_pcb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]
2024-01-11 removed mtbquery file, updated board definitions for new board
2024-01-13 updated SPI touch buffers, switch makefile to release
2024-02-05 changed SPI code to be non blocking
